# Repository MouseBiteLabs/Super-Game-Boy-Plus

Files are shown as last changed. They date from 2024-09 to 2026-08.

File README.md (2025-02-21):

# Super Game Boy Plus (SGB+)

The Super Game Boy (SGB) was a special cartridge for the Super Nintendo (SNES) that allowed you to play original Game Boy (DMG) games on your Super Nintendo... in **living color!** Some Game Boy games can even take advantage of enhancements provided by the SGB in ways you wouldn't see on a Game Boy, including custom color palettes, enhanced audio, and screen borders. *How does that strike you??*

<p align="center">
<a href="https://youtu.be/XTdGBMhjJ7U?si=7-TzK-MHGgorscUb&t=6">Brace yourself...</a> 
</p>

Unfortunately, the original Super Game Boy had one "major" flaw. The clock speed was 2.4% too fast. For most people, this makes no difference, but for *true gamers* it amounts to blasphemy. The side effect of this is that the Super Game Boy cannot use a link cable to connect with other Game Boys, since the clock speeds would be too dissimilar. Japan got the Super Game Boy 2, which fixed this oversight and added a link port. But everyone else never got it! Thus, true gamers got to work, and created mods that fix the <a href="https://www.qwertymodo.com/hardware-projects/snes/super-game-boy-clock-mod">clock speed</a> and <a href="https://www.qwertymodo.com/hardware-projects/snes/super-game-boy-link-port">add a link port</a>.

Another type of mod that has cropped up over the years <a href="https://www.timeextension.com/news/2023/08/classic-pokemon-games-get-ported-to-snes-by-industrious-fan">are standalone SNES games with a single Game Boy game inside.</a> This generally includes taking the PCB out of a Super Game Boy, taking the PCB out of a Game Boy game (hopefully a reproduction and not an original!), and permanently soldering the Game Boy PCB to the SGB board. A bit rough, but it gets the job done.

The thing about all these different SGB mods is that they consist of boards soldered together to an original SGB board. There hasn't been a single, clean, standalone board that incorporates all these features in a nice, sturdy package. Until now!



This is the Super Game Boy Plus, or SGB+. This circuit board can do the following:

- Allows for three separate clock options:
  1) the original "wrong" clock speed,
  2) the correct clock speed, or
  3) **the correct clock speed with the ability to overclock and underclock in-game**
- Incorporates the link port onto the board using a small daughter board to offset it into a perfect location on the edge of a standard SNES cartridge (if you are using an SGB2 shell, it will fit without the daughter board)
- Optionally allow you to lock the board to one specific Game Boy game instead of using the cartridge connector - save data can be transplanted to/from the cartridge via the FRAM chip
- Can be used in three different SNES shells with minimal shell trimming required:
  1) an original Super Game Boy shell with the cartridge connector,
  2) a standard 46-pin SNES shell (will require two cuts on the bottom of the shell for the extra cart edge pins), and
  3) a 60-pin SNES shell used for games that used enhancement chips like the SA-1 or SuperFX
 
There are two versions of the Super Game Boy Plus - one that can be used for standalone <a href="https://github.com/MouseBiteLabs/Super-Game-Boy-Cartridge/tree/main/SGB-MBC3">MBC3 games</a> (in development), and one that can be used for standalone <a href="https://github.com/MouseBiteLabs/Super-Game-Boy-Cartridge/tree/main/SGB-MBC5">MBC5 games</a>. If you only want an enhanced Super Game Boy without locking it to a single game, you can use *either* the MBC3 or MBC5 variant - it does not matter which you pick. Because this project is highly customizable, you must carefully follow the instructions below to help guide you through the assembly process based on your desires. 

**PLEASE READ THIS GITHUB REPOSITORY IN IT'S ENTIRETY TO ENSURE YOU ASSEMBLE THE CARTRIDGE PROPERLY.**

All gerbers and source files can be found in this repo in the two folders linked above, as this project is fully open source.

## Important Things Before You Start

1) This project requires you remove some components from an original Super Game Boy cartridge. This will require a hot air rework station or a hot plate. This will also require extensive soldering capabilities - do not attempt this project if you do not have sufficient soldering experience.
2) If you are making a single game without the cartridge connector, you need to have an original Game Boy game that uses an MBC3 or MBC5 mapper chip, so you can remove it and use it on this board. <a href="https://catskull.net/gb-rom-database/">You can find a list of games and their mappers here</a>.
3) When soldering parts on, it's a good idea to put kapton tape or otherwise cover the bottom cartridge edge. You do not want to get solder on the cartridge contacts.
4) I am not responsible for any damage you do to your self or your property. Attempt this project at your own risk.
5) I do not guarantee design compatibility. You may encounter issues with certain games. There is also a chance I have made an error in the design or the BOM - if this is the case, I will do everything I can to address the problem as quickly as possible.
6) If you are using this board to make games other than for personal use, you must have permission from the originator to use and distribute any ROM images or other related material. You are responsible for making sure you adhere to any license requirements.

DO NOT use my circuit boards for profiting from stolen work - this especially includes homebrew content, ROM hacks, and using fan-made labels without permission from the originator. **Support ALL original creators!**

## Required Equipment

- You will need basic tools, like a soldering iron, hot plate, and/or hot air rework station.
- If you need the cartridge connector for an enhanced SGB build, <a href="https://hackaday.com/2017/04/03/have-you-ever-tried-desoldering-needles/">desoldering needles</a> may be helpful in removing it from the donor board.
- If you're making a single-game SGB+ cartridge, you will need a method of programming the ROM and FRAM (if desired). You *cannot* program the SGB+ cartridge with a cart programmer, like the OSCR. You need to solder pre-programmed chips.
  - In my opinion, the easiest way to do this if you have the equipment already is to make <a href="https://github.com/MouseBiteLabs/Game-Boy-Cartridges/tree/main/MBC5%20(Type%20A%2C%20FRAM)">one of my FRAM-enabled Game Boy cartridges,</a> and then transfer the ROM and FRAM chips over to the SGB+ board. You can use a variety of cart flashers, such as <a href="https://www.gbxcart.com/">GBxCart</a> and the <a href="https://github.com/sanni/cartreader">OSCR</a> to load the game and save data onto the catridge. Doing it this way, you can also test the game in a Game Boy before you move the chips over to make sure it's in working order. As a bonus, all of the parts on the FRAM board are named *the same* as on the SGB+ board, making part transferrals even easier to manage.
  - Alternatively, the <a href="https://xgecu.myshopify.com/products/xgecu-new-t48-tl866-3gprogrammer-v12-01-support-28000-ics-for-spi-nor-nand-flash-emmc-bga153-162-169-100-221-tsop-sop-plcc">T48 programmer</a> with the <a href="https://xgecu.myshopify.com/products/100-original-xgecu-adp_f48_ex-1-tsop48-special-adapter-for-nor-flash-only-use-on-t48-tl866-3g-programmer">TSOP48 adapter</a> can program the ROM chip.
- If you want to add clock control options (overclocking/underclocking), you will need a way of programming an ATTINY85. My preferred method is to use an <a href="https://store-usa.arduino.cc/collections/boards-modules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">Arduino Uno or Arduino Mega</a>, as I own those already. The instructions I provide will be using an Arduino to program the ATTINY. There are a multitude of other ways as well, but you will need to figure those out for yourself.
- You may need to do some shell cuts to get things to fit, like the link port. I recommend using a file set - <a href="https://www.amazon.com/gp/product/B07R3R9461">I bought this one.</a> 

## Parts from an Original Super Game Boy

These are listed in the BOMs in the MBC3 and MBC5 folders, but for quick reference, you will need:

1) Super Game Boy CPU
2) ICD2 Interface chip
3) SNES Mask ROM (bottom right chip)

These parts are salvagable from the SGB (recommended), but there are alternate options listed in the BOM:
1) 2x SRAM
2) CIC Region Lockout (the 18-pin device in the middle)

PXL_20240821_180204717 MP2

## Assembly Guide

To start off, here is a bird's-eye view of the process to populate one of these boards. Please follow this flowchart as you go. I *highly* recommend testing the board in a SNES after you solder the Group A components. This will help narrow down issues early on, before you start messing with things like overclocking.

<p align="center">

</p>

### Step 1: Getting the Boot Screen

First, populate the entire board with the Group A components. That's the majority of them. Also, solder the CLK1 solder pads on the back of the board to enable the SNES-driven clock just for testing. When you pop it into the SNES (obviously without a Game Boy game), you should see this screen:



If you've got that, then you know you at least got the essentials soldered properly. If you get the Game Boy border, but no cartridge error, then you have some kind of problem somewhere on the GB-side (like the SGB CPU, the ICD2, the RAM chips, etc). If you just get a fully black screen, then either the cartridge might not be making good contact with the SNES cartridge connector (or the cart connector is dirty), or you have some issue with the SNES-side components like the mask ROM or the CIC (if you're using the PIC12F629, make sure the SuperCIC code is programmed properly). You may also have a solder bridge *anywhere* on the board.

### Step 2: Choosing the Clock Generation Method

If you're not planning on fixing the clock speed, and keeping it at the incorrect 4.295 MHz frequency, then you don't have to do anything else for this step. Skip ahead to Step 3! Otherwise, read on.

Note that for all of these clock options, you can populate Group B and C components at the same time without causing any issues. The CLK pads on the back of the board will dictate which of these components have control over the clock generation, and they can't interfere with each other (as long as you only bridge one set of CLK pads).

#### Option 1: Fixed Clock Speed

This is the simplest clock modification, all you have to do is solder the few Group B components, desolder CLK1, and solder bridge CLK2. This will yield the proper clock speed of 4.194 MHz.

#### Option 2: Clock Control With ATTINY85

This one will take some work, because you will need to program the ATTINY85. <a href="https://github.com/MouseBiteLabs/Super-Game-Boy-Cartridge/blob/main/SGB_Clock_Control_ATTINY.ino">You will need to program it with my custom-developed code.</a> You can do this before soldering, or after soldering if you use the ISP header pins. In either case, populate Group C components, desolder CLK1, and solder bridge CLK3 to set up the board for the clock generator.

I will briefly walk through how to program the ATTINY85 after it is soldered to the board, through the ISP header pins, with an Arduino Mega, but you should closely follow the guides I link. If you ask me how to program the chip, or why it isn't programming properly, my answer is going to be "read the tutorial." If you are using a different method of programming, you will have to find instructions yourself.

<a href="https://www.instructables.com/How-to-Program-an-Attiny85-From-an-Arduino-Uno/">Here is detailed instructions for using an Arduino Uno to program an ATTINY85.</a> I haven't used them myself, but they look to be correct. I personally use a Mega to program my ATTINY chips; <a href="https://www.instructables.com/How-to-Burn-ATTiny85-Using-Arduino-Mega/">the detailed instructions can be found here for the Arduino Mega.</a> Again, it is crucial you follow these instructions closely to get it working.

One thing I have done differently than these tutorials in the first steps is the choice of ATTINY core, which you need to communicate with the ATTINY through the Arduino IDE. I use ATTinyCore by SpenceKonde, <a href="https://github.com/SpenceKonde/ATTinyCore">which you can find here</a>. I recommend using this one instead.

Anyway, here's a general guideline for programming the chip:

1. Program the host Arduino to be an ISP programmer. If using the Mega, follow the instructions in the link above to change the pin definitions in the ArduinoISP code to match the Mega instead of the Uno.
2. Put SW1 in PROG mode to allow programming of the ATTINY85.
3. Connect the Arduino pins to the ISP header as such:
  - Connect ISP pin 1 (PB1, PICO on the ATTINY85) to Arduino PICO pin (50 on Mega, 12 on Uno)
  - Connect ISP pin 2 (5V) to the Arduino 5V pin
  - Connect ISP pin 3 (PB2, SCK on the ATTINY85) to Arduino SCK pin (52 on Mega, 13 on Uno)
  - Connect ISP pin 4 (PB0, POCI on the ATTINY85) to Arduino POCI pin (51 on Mega, 11 on Uno)
  - Connect ISP pin 5 (RST, SS on the ATTINY85) to Arduino SS pin (53 on Mega, 10 on Uno)
  - Connect ISP pin 6 (GND) to the Arduino GND pin
4. **Burn the bootloader to the ATTINY85** (Tools > Burn Bootloader). Make sure the processor is set to run on the internal 8 MHz clock, *not* an external clock. Not burning the bootloader is a common cause of failure when people are trying to program these chips.
5. Upload the Arduino sketch provided above onto the ATTINY85. When programming the ATTINY, my drop down menu looks like this:



6. If it uploads correctly, unplug all the wires and **switch SW1 to PLAY mode.** It will not work if it remains in PROG mode.

Remember, if you put the cartridge in your SNES and get a Game Boy border but *no blinking cartridge error* then that means there's an issue with the clock. You will know you did it right if you get the blinking error screen posted above.

#### Option 3: Qwertymodo's Clock Mod

If you don't want to deal with an ATTINY85, the board is fully compatible with <a href="https://www.qwertymodo.com/hardware-projects/snes/super-game-boy-clock-mod">qwertymodo's SGB clock mod</a>. The downside to this is that if you want to change the clock speed, you will still need to buy the Super Game Boy Commander controller from Hori... and those are *not* cheap. The main draw to qwertymodo's mod under normal circumstances is the clock speed is fixed, however since you can fix it pretty easily by soldering in the Group B components, the usefulness is a bit diminished. But in any case, it is still an option. All you have to do is follow the instructions on his site to install it, they apply to my SGB+ boards as well. Make sure the CLK1 pads remain bridged.

### Step 3: Adding a Link Port

Please note that if you want to add the link port, you *must* be using one of the clock options that fix the frequency (this also includes the overclocking option with the ATTINY85, as that defaults to 4.194 MHz). The link port *will not work* if your clock speed is the incorrect 4.295 MHz provided by the SNES.

Firstly, if for some reason you have a junked Japanese-only SGB2 cartridge with an in-tact shell (the blue one that has a cutout for the link port) then you only need to add the link port in the P1 socket. Again, though, the SGB2 is *not* compatible with this mod, so don't buy one as a donor, because you can't use it for parts.



<a href="https://gbhwdb.gekkio.fi/consoles/sgb2/">*Image from gekkio's Game Boy Hardware Database.*</a>

If you are NOT using an SGB2 shell, which I would guess you are not then you'll need to offset the link port from the board vertically to get it to fit in the shell nicely. You will also need to cut out a hole in the SNES shell, obviously.

**PLEASE NOTE: This method will NOT work for Super Famicom or PAL region Super Game Boy cartridges - only for North American SGBs.**



Getting the link port adapter board to sit level is a bit tricky. You also need to make sure the board is placed in the correct way, and not flipped around. The way I do it is:

1) Solder the 2x3 headers (these have 2mm spacing instead of the standard 2.54mm spacing) into the link port adapter board. Make sure the headers are soldered onto the adapter board in such a way that it would be sandwiched between the main PCB and the adapter PCB.


 
2) Solder the 1x2 header (these have the standard 2.54mm spacing) onto the SGB+ board. You will also need to remove the black housing, as that is thicker than the housing on the 2x3 header (which is 1.5mm), so the board would be crooked if this was kept in. Use flush cutters or some other tool to carefully remove them without bending the pins.



3) Optional - place the <a href="https://github.com/MouseBiteLabs/Super-Game-Boy-Cartridge/blob/main/linkadapter_spacer.stl">3D printed spacer I have linked above</a> on top of the SGB+ board to help level the adapter board. If you don't have a 3D printer, you can use *another* link adapter board as a temporary shim (if you get them in the 1.6mm thickness) to achieve approximately the same effect.

4) With the adapter board placed on the main SGB+ board, finish soldering the eight pins - I like to solder the two structural headers, then flip the board over and do the remaining six pins going into the P1 socket on the SGB+ board. Trim down the structural header pins after you're done.



5) Finally, solder the link port onto the adapter board, making sure it's also placed in the right direction on the correct side of the board.

This is how it should look from the "topside" of the board. (Note that this picture does not include the 3D printed spacer.)



I detail shell trimming farther down.

### Step 4: Adding the Game Boy Components

If you're planning on retaining the cartridge connector in your build, then solder in the cartridge connector now! I recommend taking the time to clean it out with some isopropyl alcohol to get better contact with Game Boy carts, since you've got it outside the shell anyway. Then, you're done! (This is the only Group E component)



If you're planning on locking the cartridge to a single game, then you have some more work to do. You need to program the M29F160 chip with the ROM of the game you want to make. You can do this in one of two ways:

1) With a standalone programmer like the <a href="https://xgecu.myshopify.com/products/xgecu-new-t48-tl866-3gprogrammer-v12-01-support-28000-ics-for-spi-nor-nand-flash-emmc-bga153-162-169-100-221-tsop-sop-plcc">T48 programmer</a> with the <a href="https://xgecu.myshopify.com/products/100-original-xgecu-adp_f48_ex-1-tsop48-special-adapter-for-nor-flash-only-use-on-t48-tl866-3g-programmer">TSOP48 adapter</a> - just place the chip in the adapter, load the ROM file in the programming software, and flash the chip

OR

2) Build a Game Boy cartridge that uses the M29F160 (like my FRAM MBC3 boards, or <a href="https://github.com/MouseBiteLabs/Game-Boy-Cartridges/tree/main/MBC5%20(Type%20A%2C%20FRAM)">FRAM MBC5 boards</a>), flash the game using a cart flasher like the <a href="https://www.gbxcart.com/">GBxCart</a> or the <a href="https://github.com/sanni/cartreader">OSCR</a>, then desolder the chips and move them over to the SGB+ board. Note that for my FRAM boards, I use the same reference designators on the Game Boy boards as I do on these SGB+ boards, making matching up the parts a lot easier if you're transferring them over. *(Note: the following picture is an old design where the reference designators are different. Ignore it!)*



The upside to #2 is that you can test the game out in an actual Game Boy before transferring the chips over, and you can flash save data onto the FRAM if you have a game already started on a different cartridge you've dumped. So personally, I use method #2 if I can.

After you've programmed your ROM (and optionally FRAM) chip(s), then solder them to the board, along with the rest of the Group F components.

**Note: The board will not fit in a Super Game Boy shell if you have soldered in the Group F components.**



At this point - you've completed assembly of the cartridge electronics! Test it in a SNES to make sure it works properly.

## Shell Trimming

As mentioned, other than the SGB2 shell, there are three different shells this circuit board is compatible with: an original Super Game Boy shell with the cartridge connector, a standard 46-pin SNES shell, and a 60-pin SNES shell used for games that used enhancement chips like the SA-1 or SuperFX. This section will go over the (potential) shell cuts you may need for your build, depending on what features you're including and which shell you're using. (Spoiler alert: the 60-pin shells require the fewest amount of cuts.)

### Super Game Boy Shell Trimming (for Link Port)

Along with the trimming below for the link port, you will need to do a few minor trims on the SGB shell if you're making an enhanced SGB cartridge, that I recommend tackling first before you move onto the big trim.

There's this ridge here near where the link port will be going on the back shell. This doesn't need to be an extremely clean cut.



On the front shell, you will also need to trim off this post, as it interferes with the link port board.



Now to cover the actual trimming required for letting the link port stick out, which will be applicable to all the shell types.

### Link Port Shell Trimming

If you are adding a link port, and you aren't using an SGB2 shell, you will need to do a cut on every shell to accomodate the link port. <a href="https://github.com/MouseBiteLabs/Super-Game-Boy-Cartridge/blob/main/linkport_cut_guide.stl">I've created a 3D model you can 3D print in order to help line up the cut you need to make</a>; it is also linked at the top of this repository. The print sits on top of the shell and has a cutout where you can start your cut for the link port. Note that this is **only** a starting point. You will need to shave back the shell more to get it to fit - go slowly, be patient, or you will get ugly cuts. Cut the area highlighted in yellow below.



You should also do a cut on the *top* half of the shell, where the link port will sit, to make sure it closes nicely. I don't have a guide made up for this one, since it's a pretty minor cut. Just line it up, and shave off the section.



### Standard 46-pin SNES Shell Cuts

Standard SNES shells only have one cut on the bottom of the shell to allow the middle 46 cart edge pins to stick through. But the Super Game Boy uses the extra 16 expansion pins on either end. So you'll have to cut two slots for those parts of the cart edge to stick through. The easiest way I've been able to do this is to line up the middle 46 pins, and sit the board a bit above that so you can see the plastic you'll need to cut. Then, mark the area you'll have to cut with a marker, and go over it with a file. I *highly* recommend against using flush cutters to make a starting cut, because the plastic will snap off really easily all the way towards the middle, and you'll be missing the two little nubs.





## Game Controls

Since this is still a Super Game Boy... probably just good to look at the <a href="https://archive.org/details/nintendo-snes-super-game-boy/mode/2up">Super Game Boy manual</a> for all the controls that go with that.

Other than that - if you've installed the clock mod onto your board, this is how you control it if you use the code I provide. You only need to use the Start and Select buttons to change speeds. In the code, I have allocated space for seven different clock settings, and it starts at 1x by default (the correct 4.194 MHz clock speed). Note that each clock speed will affect the audio as well - it is not like Dodrio mode in Pokemon Stadium's GB Tower where the audio is unaffected. This means playing games can get... annoying at really high clock speeds.

The default clock multiplier settings are in order: 0.5x, 0.67x, 0.8x, 1x, 1.25x, 1.5x, 2x. A clock multiplier of 3x works, but produces a lot of graphical glitches. 4x and higher becomes unstable and will freeze the game.

- Speeding up: Press and hold Select first, wait a second, then also press and hold Start simultaneously (imitating a "fast forward" button)
- Slowing down: Press and hold Start first, wait a second, then also press and hold Select simultaneously (imitating a "rewind" button)
- Continuing to hold these two buttons down will continue up/down the list of clock multipliers in the code until it hits the maximum/minimum, with approximately a 2 second delay between switching





If you want, you can also disable the clock change function, allowing you to use the Start and Select buttons freely (though, I can't think of any game that requires you press these buttons simultaneously for longer than a few seconds). To do this:

- Press and hold both Start *and* Select at the same time and hold down for approximately 5 seconds.
- If your clock speed is something other than the 1x setting, it will be reset back to 1x.
- At this point, you have disabled the clock change function: **pressing Start/Select will no longer change the clock speed.**
- To re-enable clock control, press and hold Start *and* Select at the same time and hold down for approximately 5 seconds.

Power cycling the SNES will also re-enable the clock control function.

## FAQ

**Q: Will these boards fit in Super Famicom shells?**

A: I am pretty sure they do, but I don't have any to try out. If you're able to confirm they fit for me, please let me know, and I will update this question accordingly.

**Q: Does this work with a DMG CPU instead of a SGB CPU?**

A: Unfortunately, no, but it would be really nice if you could.

**Q: Does this work with a SGB2 CPU instead of a SGB CPU?**

A: No, please do not destroy a SGB2 for this project!

**Q: Can you make one for me?**

A: No.

**Q: But what if I pay you?**

A: **NO.**

**Q: Can I make Game Boy Color games with this?**

A: No.

**Q: Can you make a board that lets you play Game Boy Color games on the SNES?**

A: Not without FPGA wizardry, which is something I don't want to deal with.

## Resources and Acknowledgements

- Enormous thanks to Gekkio for their Super Game Boy reverse engineering work. <a href="https://github.com/Gekkio/gb-schematics/tree/main/SGB-R-xx_SGB-N-xx">This repository</a> was the basis of this project, and he saved me hours and hours of time. He is the hero we don't deserve.
- <a href="https://www.qwertymodo.com/">Qwertymodo</a>'s work with the clock mod and link port additions really helped me out in designing my own. Huge thanks for his findings, and all he has contributed to the gaming space!
- Thanks to Adafruit for providing the basis of the <a href="https://learn.adafruit.com/adafruit-si5351-clock-generator-breakout/overview">clock generator circuit.</a>
- Special thanks to beta tester olDirdey from discord, for providing some feedback on the link port and suggesting the 2-pin structural support header.

## License

<br />This work is licensed under a <a rel="license" href="http://creativecommons.org/licenses/by-sa/4.0/">Creative Commons Attribution-ShareAlike 4.0 International License</a>. You are able to copy and redistribute the material in any medium or format, as well as remix, transform, or build upon the material for any purpose (even commercial) - but you **must** give appropriate credit, provide a link to the license, and indicate if any changes were made.

©MouseBiteLabs 2024

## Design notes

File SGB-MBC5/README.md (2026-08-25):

# MBC5 Variant

This board is the MBC5 variant, useful for making standalone MBC5-based Game Boy games for the Super Nintendo. You can *also* use this board *completely without* the Game Boy parts to make an enhanced SGB board with link port and modified clock.

## Board Characteristics and Order Information

The zipped folder contains all the gerber files for this board. The following options **must** be chosen when ordering boards for yourself.

- Thickness: 1.2mm
- Layers: 4
- Surface Finish: ENIG
- Gold Fingers: Yes, 30° chamfer

You can use the zipped folder at any board fabricator you like. You may also buy the board from PCBWay using this link (disclosure: I receive 10% of the sale value to go towards future PCB orders of my own):

<a href="https://www.pcbway.com/project/shareproject/Super_Game_Boy_Plus_2783d5a1.html">PCB from PCBWay</a>

**PLEASE NOTE: I have not ordered these from PCBWay, so I cannot attest to their quality or performance. I have put the order details in as I believe they should be, but you need to review all parameters before ordering. Order at your own risk.**

### Purchase from My Website

You can purchase this circuit board at my website, [https://mousebitelabs.store](https://mousebitelabs.store). Click the following image to be directed to the specific item listing:

<a href="https://mousebitelabs.store/products/super-game-boy-plus-circuit-board-mbc5">PCB from MouseBiteLabs</a>

### Purchase from Etsy

I also offer the board on Etsy, if you would rather purchase through there - click the banner to be redirected.

<a href="https://mousebitelabs.etsy.com/listing/1837439505">PCB from Etsy</a> 

## Bill of Materials (BOM)

Here's a Mouser cart that has every part you would need on the circuit board, *except* the parts you must harvest from a Super Game Boy cartridge and an MBC5 Game Boy cartridge. It also does not include a link port, since you will need to get that from aftermarket sellers (check the link in the BOM). 

If your Super Game Boy cartridge has damaged RAM chips (something that is unlikely, but possible), you will also need to add the RAM chips listed in the BOM.

https://www.mouser.com/ProjectManager/ProjectDetail.aspx?AccessID=6f87901e1f 

If you don't need all of the component groups below, you will need to go through the cart and remove the ones you do not need. Note that the FRAM itself is >$10 at the time of writing. You can get cheaper parts from other sellers on eBay or AliExpress, but the quality is dubious, so order at your own risk.

### Group A Components (Required for Every Build)
| Reference | Value/Part Number | Package | Description | Source |
| --- | --- | --- | --- | --- |
| C1 | 0.01uF | 0603 | Capacitor (MLCC) | https://mou.sr/3AsRwK1 |
| C2 | 0.01uF | 0603 | Capacitor (MLCC) | https://mou.sr/3AsRwK1 |
| C3 | 0.01uF | 0603 | Capacitor (MLCC) | https://mou.sr/3AsRwK1 |
| C4 | 0.01uF | 0603 | Capacitor (MLCC) | https://mou.sr/3AsRwK1 |
| C5 | 0.01uF | 0603 | Capacitor (MLCC) | https://mou.sr/3AsRwK1 |
| C6 | 0.01uF | 0603 | Capacitor (MLCC) | https://mou.sr/3AsRwK1 |
| C7 | 22uF | 4mm x 5.5mm | Capacitor (ALEL) | https://mou.sr/4cVQXbO |
| C8 | 4.7uF | 4mm x 5.5mm | Capacitor (ALEL) | https://mou.sr/4cRhEhW |
| C9 | 4.7uF | 4mm x 5.5mm | Capacitor (ALEL) | https://mou.sr/4cRhEhW |
| C10 | 0.1uF | 0603 | Capacitor (MLCC) | https://mou.sr/3ENc15O |
| C11 | 0.1uF | 0603 | Capacitor (MLCC) | https://mou.sr/3ENc15O |
| C13 | 10pF | 0603 | Capacitor (MLCC) | https://mou.sr/3XA5J3N |
| C14 | 10pF | 0603 | Capacitor (MLCC) | https://mou.sr/3XA5J3N |
| C15 | 33pF | 0603 | Capacitor (MLCC) | https://mou.sr/4cYZLxw |
| C16 | 51pF | 0603 | Capacitor (MLCC) | https://mou.sr/3XjvPGV |
| C17 | 51pF | 0603 | Capacitor (MLCC) | https://mou.sr/3XjvPGV |
| C18 | 0.01uF | 0603 | Capacitor (MLCC) | https://mou.sr/3AsRwK1 |
| R1 | 510k | 0603 | Resistor | https://mou.sr/3zi8ayj |
| R2 | 910 | 0603 | Resistor | https://mou.sr/4gj68i7 |
| R3 | 910 | 0603 | Resistor | https://mou.sr/4gj68i7 |
| R4 | 220 | 0603 | Resistor | https://mou.sr/3ARwrf3 |
| R5 | 220 | 0603 | Resistor | https://mou.sr/3ARwrf3 |
| R6 | 220 | 0603 | Resistor | https://mou.sr/3ARwrf3 |
| R7 | 510 | 0603 | Resistor | https://mou.sr/3IJHtni |
| R8 | 10k | 0603 | Resistor | https://mou.sr/3riR7IH |
| R9 | 330 | 0603 | Resistor | https://mou.sr/3PWP8Ti |
| R10 | 330 | 0603 | Resistor | https://mou.sr/3PWP8Ti |
| R11 | 330 | 0603 | Resistor | https://mou.sr/3PWP8Ti |
| R12 | 330 | 0603 | Resistor | https://mou.sr/3PWP8Ti |
| R13 | 330 | 0603 | Resistor | https://mou.sr/3PWP8Ti |
| R14 | 330 | 0603 | Resistor | https://mou.sr/3PWP8Ti |
| R15 | 330 | 0603 | Resistor | https://mou.sr/3PWP8Ti |
| R16 | 330 | 0603 | Resistor | https://mou.sr/3PWP8Ti |
| R28 | 10k | 0603 | Resistor | https://mou.sr/3riR7IH |
| U1 | CPU SGB | QFP-80 | Super Game Boy CPU | Donor Super Game Boy |
| U2 | ICD2 | QFP-44 | SGB-SNES Interface Chip | Donor Super Game Boy |
| U3 | LH52A64N / AS6C6264 | SOIC-28 | 64K SRAM | Donor Super Game Boy / https://mou.sr/4cWBw3f |
| U4 | LH52A64N / AS6C6264 | SOIC-28 | 64K SRAM | Donor Super Game Boy / https://mou.sr/4cWBw3f |
| U5 | SYS-SGB | SOIC-32 | Mask ROM (SNES) | Donor Super Game Boy |
| U6 | CIC / PIC12F629 | SSOP-18 / SOIC-8 | Lockout Chip | Donor Super Game Boy / https://mou.sr/4dSUh90 |

### Group B Components (For a Fixed 4.194304 MHz Clock)
| Reference | Value/Part Number | Package | Description | Source |
| --- | --- | --- | --- | --- |
| C23 | 27pF | 0603 | Capacitor (MLCC) | https://mou.sr/3XiK3HJ |
| C24 | 27pF | 0603 | Capacitor (MLCC) | https://mou.sr/3XiK3HJ |
| R18 | 1M | 0603 | Resistor | https://mou.sr/3xhFdS3 |
| X1 | 4.194304 MHz | HC-49/US | Crystal Oscillator | https://mou.sr/3yXaoDq |

### Group C Components (For a Fixed 4.194304 MHz Clock, with Overclocking and Underclocking)
| Reference | Value/Part Number | Package | Description | Source |
| --- | --- | --- | --- | --- |
| C30 | 1uF | 0603 | Capacitor (MLCC) | https://mou.sr/47lY3oP |
| C31 | 0.1uF | 0603 | Capacitor (MLCC) | https://mou.sr/3ENc15O |
| C32 | 0.1uF | 0603 | Capacitor (MLCC) | https://mou.sr/3ENc15O |
| C33 | 0.1uF | 0603 | Capacitor (MLCC) | https://mou.sr/3ENc15O |
| Q1 | BSS138 | SOT-23 | MOSFET (N-ch) | https://mou.sr/3TjlOs3 |
| Q2 | BSS138 | SOT-23 | MOSFET (N-ch) | https://mou.sr/3TjlOs3 |
| SW1 | CAS-220A1 | A-type | DPDT | https://mou.sr/4ewSJSb |
| U11 | NCP161ASN330T1G | SOT-23-5 | 3.3V Regulator | https://mou.sr/3iqSHDt |
| U12 | Si5351A-B-GT | MSOP-10 | Clock Generator | https://mou.sr/3Wyr1LG |
| U13 | ATTINY85 | SOIC-8 | Microcontroller | https://mou.sr/3OpMtBA |
| X2 | 25.000 MHz | 3.2mm x 2.5mm | Crystal Oscillator | https://mou.sr/3MAK5pD |

### Group D Components (For Adding a Link Port)
| Reference | Value/Part Number | Package | Description | Source |
| --- | --- | --- | --- | --- |
| A1 | Link Adapter PCB v1.3 | N/A | Adapter circuit board | |
| C25 | 100pF | 0603 | Capacitor (MLCC) | https://mou.sr/47fshd2 |
| C26 | 100pF | 0603 | Capacitor (MLCC) | https://mou.sr/47fshd2 |
| C27 | 100pF | 0603 | Capacitor (MLCC) | https://mou.sr/47fshd2 |
| C28 | 100pF | 0603 | Capacitor (MLCC) | https://mou.sr/47fshd2 |
| C29 | 0.01uF | 0603 | Capacitor (MLCC) | https://mou.sr/3AsRwK1 |
| D1 | BAV99S | SOT-363 | Dual series diodes | https://mou.sr/3X97NOE |
| D2 | BAV99S | SOT-363 | Dual series diodes | https://mou.sr/3X97NOE |
| D3 | ES07D | SMF | Diode | https://mou.sr/3XdX1Xr |
| J1 | 610106249121 | 2x3, 2.54mm spacing, right angle | Programming header | https://mou.sr/3XygS4Z |
| J2 | G800WC306018EU | 1x2, 2.54mm spacing | Header pins (structural) | https://mou.sr/3yXak6E |
| J3 | 2MM-HB-D03-VT-02-H-TB | 2x3, 2mm spacing | Header pins (link port PCB) | https://mou.sr/3TfU2wA |
| P2 | Link Port | 2x3, 2mm spacing | MGB/GBC Link Port | https://tinyurl.com/m3y35e3z |
| R19 | 220 | 0603 | Resistor | https://mou.sr/3ARwrf3 |
| R20 | 220 | 0603 | Resistor | https://mou.sr/3ARwrf3 |
| R21 | 220 | 0603 | Resistor | https://mou.sr/3ARwrf3 |
| R22 | 220 | 0603 | Resistor | https://mou.sr/3ARwrf3 |
| R23 | 10k | 0603 | Resistor | https://mou.sr/3riR7IH |
| R24 | 10k | 0603 | Resistor | https://mou.sr/3riR7IH |
| R25 | 10k | 0603 | Resistor | https://mou.sr/3riR7IH |
| R26 | 10k | 0603 | Resistor | https://mou.sr/3riR7IH |
| R27 | 10k | 0603 | Resistor | https://mou.sr/3riR7IH |

### Group E Components (For an Enhanced SGB Board)
| Reference | Value/Part Number | Package | Description | Source |
| --- | --- | --- | --- | --- |
| P1 | Game Boy Cart Connector | N/A | SGB Game Boy Cart Connector | Donor Super Game Boy |

### Group F Components (For a Single-Game SGB Board)
| Reference | Value/Part Number | Package | Description | Source |
| --- | --- | --- | --- | --- |
| C19 | 0.1uF | 0603 | Capacitor (MLCC) | https://mou.sr/3ENc15O |
| C20 | 0.1uF | 0603 | Capacitor (MLCC) | https://mou.sr/3ENc15O |
| C21 | 0.1uF | 0603 | Capacitor (MLCC) | https://mou.sr/3ENc15O |
| C22 | 0.1uF | 0603 | Capacitor (MLCC) | https://mou.sr/3ENc15O |
| R17 | 10k | 0603 | Resistor | https://mou.sr/3riR7IH |
| U7 | M29F160 | TSOP-48 | Flash EEPROM (Game Boy) | https://mou.sr/3N0a9eL |
| U8 | MBC5 | QFP-32 | MBC5 Mapper | Donor Game Boy Game |
| U9 | FM18W08-SG | SOIC-28 | FRAM | https://mou.sr/4cRIJlb |
| U10 | SN74LVC1G332 | SOT-363 | 3-input Or Gate | https://mou.sr/3XdbXoN |

### Other Components - Do Not Populate
| Reference | Value/Part Number | Package | Description | Group | Source |
| --- | --- | --- | --- | ----- | --- |
| C12 | 10pF (DNP) | 0603 | Capacitor (MLCC) | DNP | https://mou.sr/3XA5J3N |
## License

<br />This work is licensed under a <a rel="license" href="http://creativecommons.org/licenses/by-sa/4.0/">Creative Commons Attribution-ShareAlike 4.0 International License</a>. You are able to copy and redistribute the material in any medium or format, as well as remix, transform, or build upon the material for any purpose (even commercial) - but you **must** give appropriate credit, provide a link to the license, and indicate if any changes were made.

©MouseBiteLabs 2024

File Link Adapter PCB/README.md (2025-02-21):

# Link Adapter PCB

Use this board to center the link port properly in SNES shells that *aren't* the SGB2.

NOTE: This only works on the North American Super Game Boy shell. It will not fit in a Super Famicom or PAL region SGB.

## Board Characteristics and Order Information

The zipped folder contains all the gerber files for this board. The board characteristics don't really matter a whole lot, but I would err on the thicker side for support purposes.

- Thickness: any
- Layers: 2
- Surface Finish: any

<a href="https://oshpark.com/shared_projects/MZ2FDhuA">Also available on OSH Park.</a>

## Board Explanation

Please review the main guide for instructions on how to install the board. Here is a quick reference for the board to help you keep it straight, and to not install it incorrectly.



## License

<br />This work is licensed under a <a rel="license" href="http://creativecommons.org/licenses/by-sa/4.0/">Creative Commons Attribution-ShareAlike 4.0 International License</a>. You are able to copy and redistribute the material in any medium or format, as well as remix, transform, or build upon the material for any purpose (even commercial) - but you **must** give appropriate credit, provide a link to the license, and indicate if any changes were made.

©MouseBiteLabs 2024

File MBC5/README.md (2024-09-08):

# MBC5 Variant

## Bill of Materials (BOM)

| Reference | Value/Part Number | Package | Description | Group | Source |
| --- | --- | --- | --- | ----- | --- |
| C1 | 0.01uF | 0603 | Capacitor (MLCC) | A | https://mou.sr/3AsRwK1 |
| C2 | 0.01uF | 0603 | Capacitor (MLCC) | A | https://mou.sr/3AsRwK1 |
| C3 | 0.01uF | 0603 | Capacitor (MLCC) | A | https://mou.sr/3AsRwK1 |
| C4 | 0.01uF | 0603 | Capacitor (MLCC) | A | https://mou.sr/3AsRwK1 |
| C5 | 0.01uF | 0603 | Capacitor (MLCC) | A | https://mou.sr/3AsRwK1 |
| C6 | 0.01uF | 0603 | Capacitor (MLCC) | A | https://mou.sr/3AsRwK1 |
| C7 | 22uF | 4mm x 5.5mm | Capacitor (ALEL) | A | https://mou.sr/4cVQXbO |
| C8 | 4.7uF | 4mm x 5.5mm | Capacitor (ALEL) | A | https://mou.sr/4cRhEhW |
| C9 | 4.7uF | 4mm x 5.5mm | Capacitor (ALEL) | A | https://mou.sr/4cRhEhW |
| C10 | 0.1uF | 0603 | Capacitor (MLCC) | A | https://mou.sr/3ENc15O |
| C11 | 0.1uF | 0603 | Capacitor (MLCC) | A | https://mou.sr/3ENc15O |
| C12 | 10pF (DNP) | 0603 | Capacitor (MLCC) | DNP | https://mou.sr/3XA5J3N |
| C13 | 10pF | 0603 | Capacitor (MLCC) | A | https://mou.sr/3XA5J3N |
| C14 | 10pF | 0603 | Capacitor (MLCC) | A | https://mou.sr/3XA5J3N |
| C15 | 33pF | 0603 | Capacitor (MLCC) | A | https://mou.sr/4cYZLxw |
| C16 | 51pF | 0603 | Capacitor (MLCC) | A | https://mou.sr/3XjvPGV |
| C17 | 51pF | 0603 | Capacitor (MLCC) | A | https://mou.sr/3XjvPGV |
| C18 | 0.01uF | 0603 | Capacitor (MLCC) | A | https://mou.sr/3AsRwK1 |
| C19 | 0.1uF | 0603 | Capacitor (MLCC) | F | https://mou.sr/3ENc15O |
| C20 | 0.1uF | 0603 | Capacitor (MLCC) | F | https://mou.sr/3ENc15O |
| C21 | 0.1uF | 0603 | Capacitor (MLCC) | F | https://mou.sr/3ENc15O |
| C22 | 0.1uF | 0603 | Capacitor (MLCC) | F | https://mou.sr/3ENc15O |
| C23 | 27pF | 0603 | Capacitor (MLCC) | B | https://mou.sr/3XiK3HJ |
| C24 | 27pF | 0603 | Capacitor (MLCC) | B | https://mou.sr/3XiK3HJ |
| C25 | 100pF | 0603 | Capacitor (MLCC) | D | https://mou.sr/47fshd2 |
| C26 | 100pF | 0603 | Capacitor (MLCC) | D | https://mou.sr/47fshd2 |
| C27 | 100pF | 0603 | Capacitor (MLCC) | D | https://mou.sr/47fshd2 |
| C28 | 100pF | 0603 | Capacitor (MLCC) | D | https://mou.sr/47fshd2 |
| C29 | 0.01uF | 0603 | Capacitor (MLCC) | D | https://mou.sr/3AsRwK1 |
| C30 | 1uF | 0603 | Capacitor (MLCC) | C | https://mou.sr/47lY3oP |
| C31 | 0.1uF | 0603 | Capacitor (MLCC) | C | https://mou.sr/3ENc15O |
| C32 | 0.1uF | 0603 | Capacitor (MLCC) | C | https://mou.sr/3ENc15O |
| C33 | 0.1uF | 0603 | Capacitor (MLCC) | C | https://mou.sr/3ENc15O |
| D1 | BAV99S | SOT-363 | Dual series diodes | D | https://mou.sr/3X97NOE |
| D2 | BAV99S | SOT-363 | Dual series diodes | D | https://mou.sr/3X97NOE |
| D3 | ES07D | SMF | Diode | D | https://mou.sr/3XdX1Xr |
| J1 | 2MM-HB-D03-VT-02-H-TB | 2x3, 2mm spacing | Header pins | D | https://mou.sr/3TfU2wA |
| J2 | G800WC306018EU | 1x2, 2.54mm spacing | Header pins | D | [https://mou.sr/3yXak6E](https://mou.sr/3yXak6E) |
| P1 | Link Port | 2x3, 2mm spacing | Link Port | D | [https://tinyurl.com/m3y35e3z](https://tinyurl.com/m3y35e3z) |
| Q1 | BSS138 | SOT-23 | MOSFET (N-ch) | C | https://mou.sr/3TjlOs3 |
| Q2 | BSS138 | SOT-23 | MOSFET (N-ch) | C | https://mou.sr/3TjlOs3 |
| R1 | 510k | 0603 | Resistor | A | https://mou.sr/3zi8ayj |
| R2 | 910 | 0603 | Resistor | A | https://mou.sr/4gj68i7 |
| R3 | 910 | 0603 | Resistor | A | https://mou.sr/4gj68i7 |
| R4 | 220 | 0603 | Resistor | A | https://mou.sr/3ARwrf3 |
| R5 | 220 | 0603 | Resistor | A | https://mou.sr/3ARwrf3 |
| R6 | 220 | 0603 | Resistor | A | https://mou.sr/3ARwrf3 |
| R7 | 510 | 0603 | Resistor | A | https://mou.sr/3IJHtni |
| R8 | 10k | 0603 | Resistor | A | https://mou.sr/3riR7IH |
| R9 | 330 | 0603 | Resistor | A | https://mou.sr/3PWP8Ti |
| R10 | 330 | 0603 | Resistor | A | https://mou.sr/3PWP8Ti |
| R11 | 330 | 0603 | Resistor | A | https://mou.sr/3PWP8Ti |
| R12 | 330 | 0603 | Resistor | A | https://mou.sr/3PWP8Ti |
| R13 | 330 | 0603 | Resistor | A | https://mou.sr/3PWP8Ti |
| R14 | 330 | 0603 | Resistor | A | https://mou.sr/3PWP8Ti |
| R15 | 330 | 0603 | Resistor | A | https://mou.sr/3PWP8Ti |
| R16 | 330 | 0603 | Resistor | A | https://mou.sr/3PWP8Ti |
| R17 | 10k | 0603 | Resistor | F | https://mou.sr/3riR7IH |
| R18 | 1M | 0603 | Resistor | B | https://mou.sr/3xhFdS3 |
| R19 | 220 | 0603 | Resistor | D | https://mou.sr/3ARwrf3 |
| R20 | 220 | 0603 | Resistor | D | https://mou.sr/3ARwrf3 |
| R21 | 220 | 0603 | Resistor | D | [https://mou.sr/3ARwrf3](https://mou.sr/3ARwrf3) |
| R22 | 220 | 0603 | Resistor | D | https://mou.sr/3ARwrf3 |
| R23 | 10k | 0603 | Resistor | D | https://mou.sr/3riR7IH |
| R24 | 10k | 0603 | Resistor | D | https://mou.sr/3riR7IH |
| R25 | 10k | 0603 | Resistor | D | https://mou.sr/3riR7IH |
| R26 | 10k | 0603 | Resistor | D | https://mou.sr/3riR7IH |
| R27 | 10k | 0603 | Resistor | D | https://mou.sr/3riR7IH |
| R28 | 10k | 0603 | Resistor | A | https://mou.sr/3riR7IH |
| SW1 | CAS-220A1 | A-type | DPDT | C | https://mou.sr/4ewSJSb |
| U1 | CPU SGB | QFP-80 | Super Game Boy CPU | A | Donor SGB |
| U2 | ICD2 | QFP-44 | SGB-SNES Interface Chip | A | Donor SGB |
| U3 | AS6C6264 | SOIC-28 | 64K SRAM | A | https://mou.sr/4cWBw3f |
| U4 | AS6C6264 | SOIC-28 | 64K SRAM | A | https://mou.sr/4cWBw3f |
| U5 | SYS-SGB | SOIC-32 | Mask ROM (SNES) | A | Donor SGB |
| U6 | CIC / PIC12F629 | SSOP-18 / SOIC-8 | Lockout Chip | A | Donor SGB / https://mou.sr/4dSUh90 |
| U7 | M29F160 | TSOP-48 | Flash EEPROM (Game Boy) | F | https://mou.sr/3N0a9eL |
| U8 | MBC5 | QFP-32 | MBC5 Mapper | F | Donor Game Boy Game |
| U9 | FM18W08-SG | SOIC-28 | FRAM | F | https://mou.sr/4cRIJlb |
| U10 | SN74LVC1G332 | SOT-363 | 3-input Or Gate | F | https://mou.sr/3XdbXoN |
| U11 | NCP161ASN330T1G | SOT-23-5 | 3.3V Regulator | C | https://mou.sr/3iqSHDt |
| U12 | Si5351A-B-GT | MSOP-10 | Clock Generator | C | https://mou.sr/3Wyr1LG |
| U13 | ATTINY85 | SOIC-8 | Microcontroller | C | https://mou.sr/3OpMtBA |
| X1 | 4.194304 MHz | HC-49/US | Crystal Oscillator | B | [https://mou.sr/3yXaoDq](https://mou.sr/3yXaoDq) |
| X2 | 25.000 MHz | 3.2mm x 2.5mm | Crystal Oscillator | C | https://mou.sr/3MAK5pD |

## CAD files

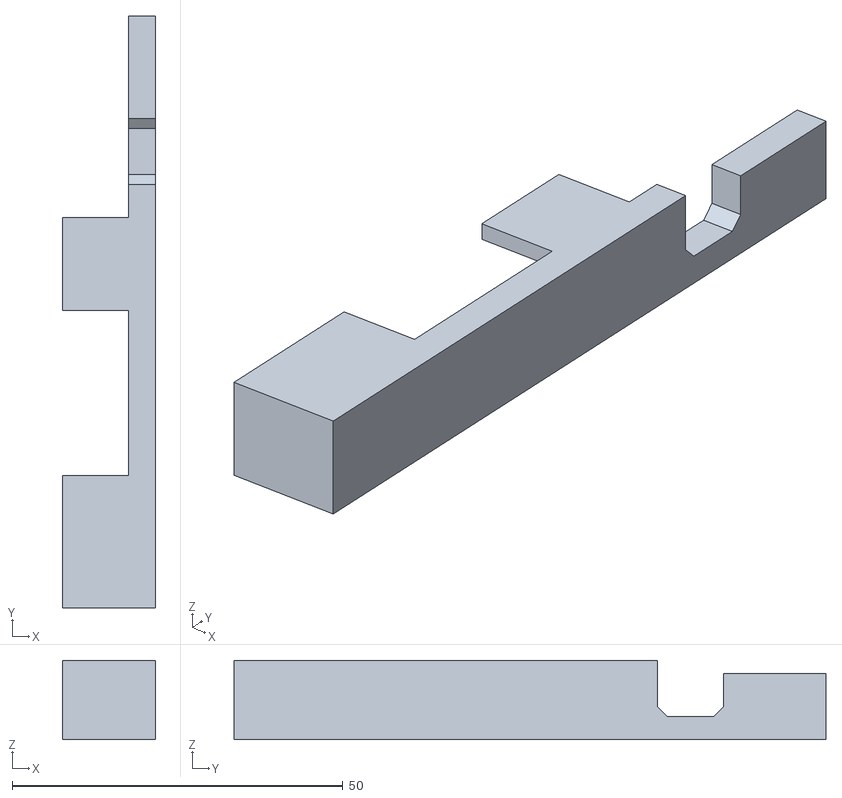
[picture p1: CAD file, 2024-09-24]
linkport_cut_guide.stl
14.1 x 89.5 x 12.0

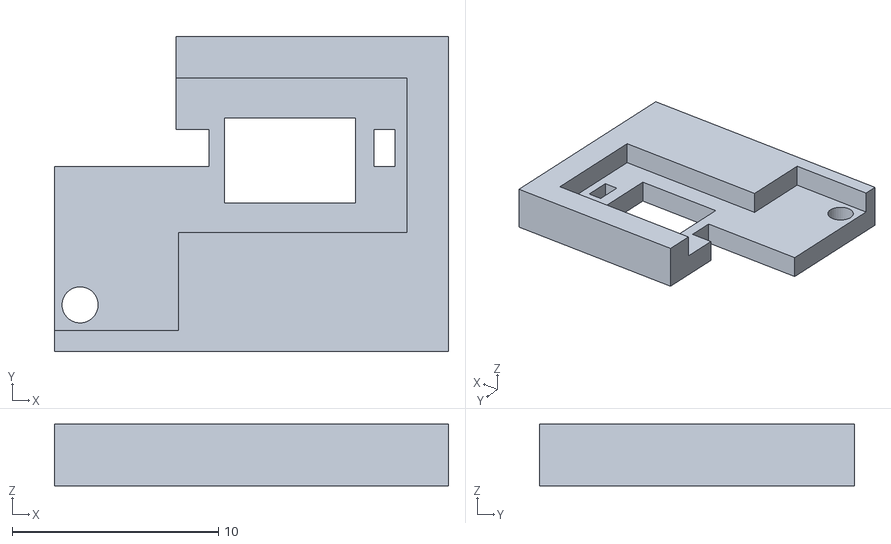
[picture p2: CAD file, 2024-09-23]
linkadapter_spacer.stl
19.1 x 15.3 x 3.00

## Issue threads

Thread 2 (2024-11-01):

External Switch to Toggle Between Internal ROM and Cartridge Slot on the Super Game Boy

FokinoPelvis, 2024-11-01:
I would like to suggest a hardware modification for the Super Game Boy Plus that could significantly enhance its usability and versatility. Specifically, I propose adding a switch on the side of the Super Game Boy's casing, with two selectable positions:

Internal ROM Mode: This position would allow users to directly access the Super Game Boy Plus’s built-in ROM, bypassing the need for a cartridge.

Cartridge Slot Mode: This position would allow the system to read any cartridge inserted into the slot, as is the current standard. Ideally, if no cartridge is inserted, the system could default back to the internal ROM. However, I understand that automating this process may present technical challenges.

This addition would enable users to effortlessly switch between internal content and cartridge games without needing complex modifications or additional tools. I believe this feature would add substantial value to the Super Game Boy Plus and offer users a more seamless gaming experience.

Thank you for considering this enhancement, and I appreciate your ongoing commitment to improving the Super Game Boy Plus.

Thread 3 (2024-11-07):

Trying to have it made through your shared project on pcbway but there are clearance problems.

noromamai, 2024-11-07:
The minimum clearance of the project files is 0.15mm, but none of their solder masks they offer can go lower than 0.19mm. Is it ok to produce the pcb without solder mask?

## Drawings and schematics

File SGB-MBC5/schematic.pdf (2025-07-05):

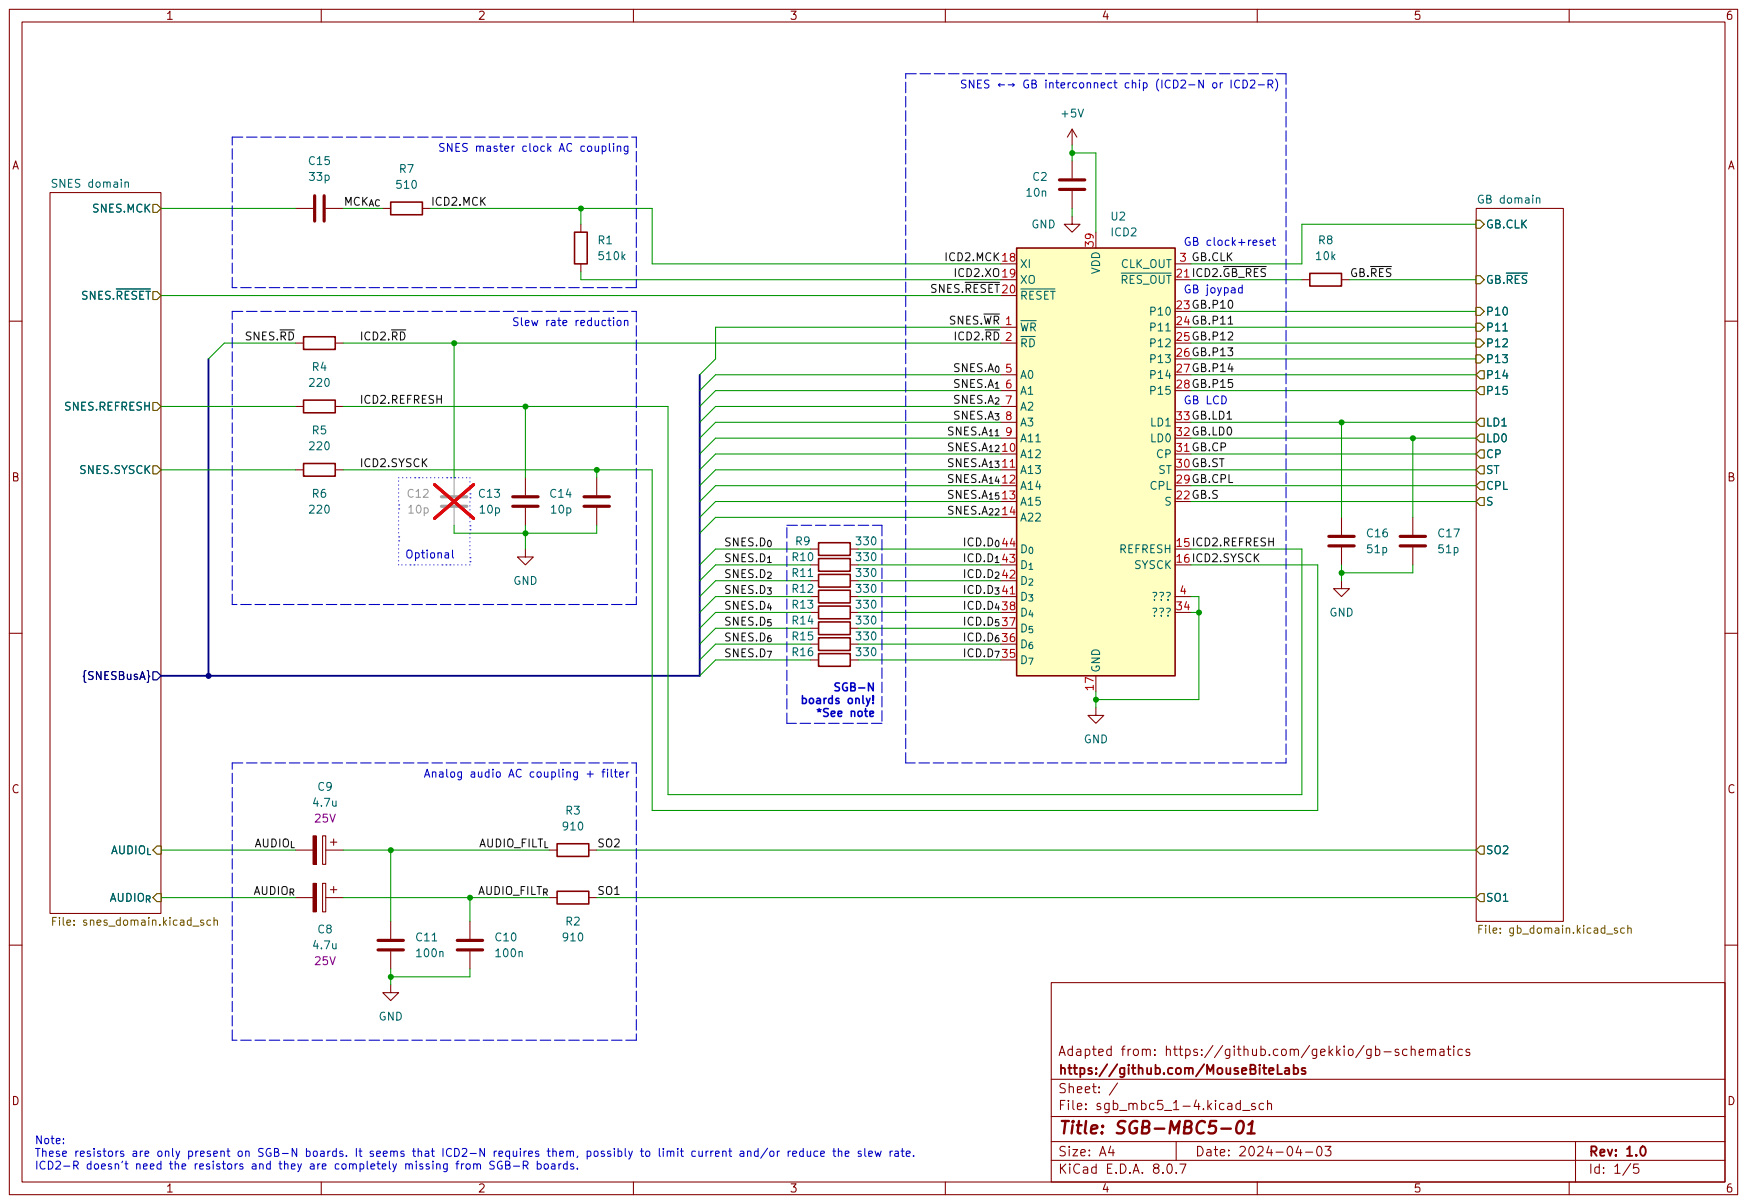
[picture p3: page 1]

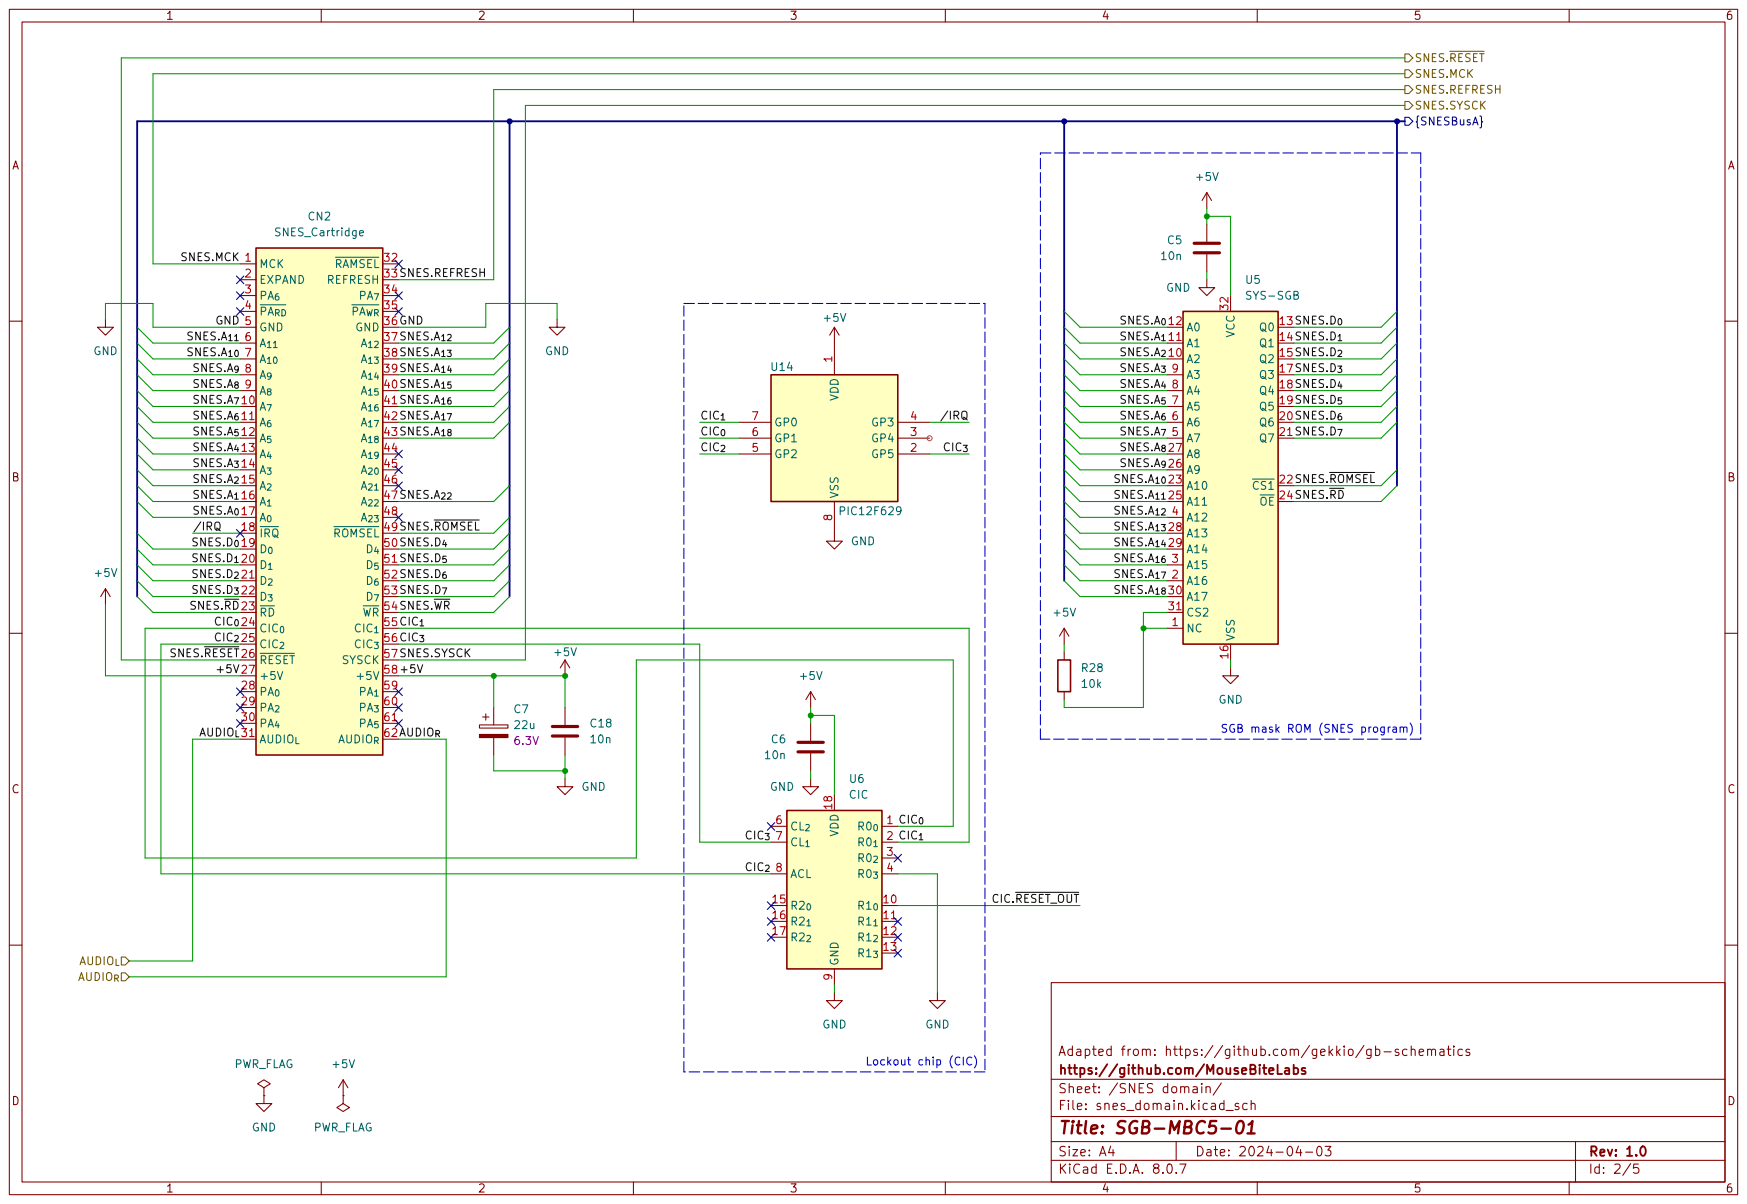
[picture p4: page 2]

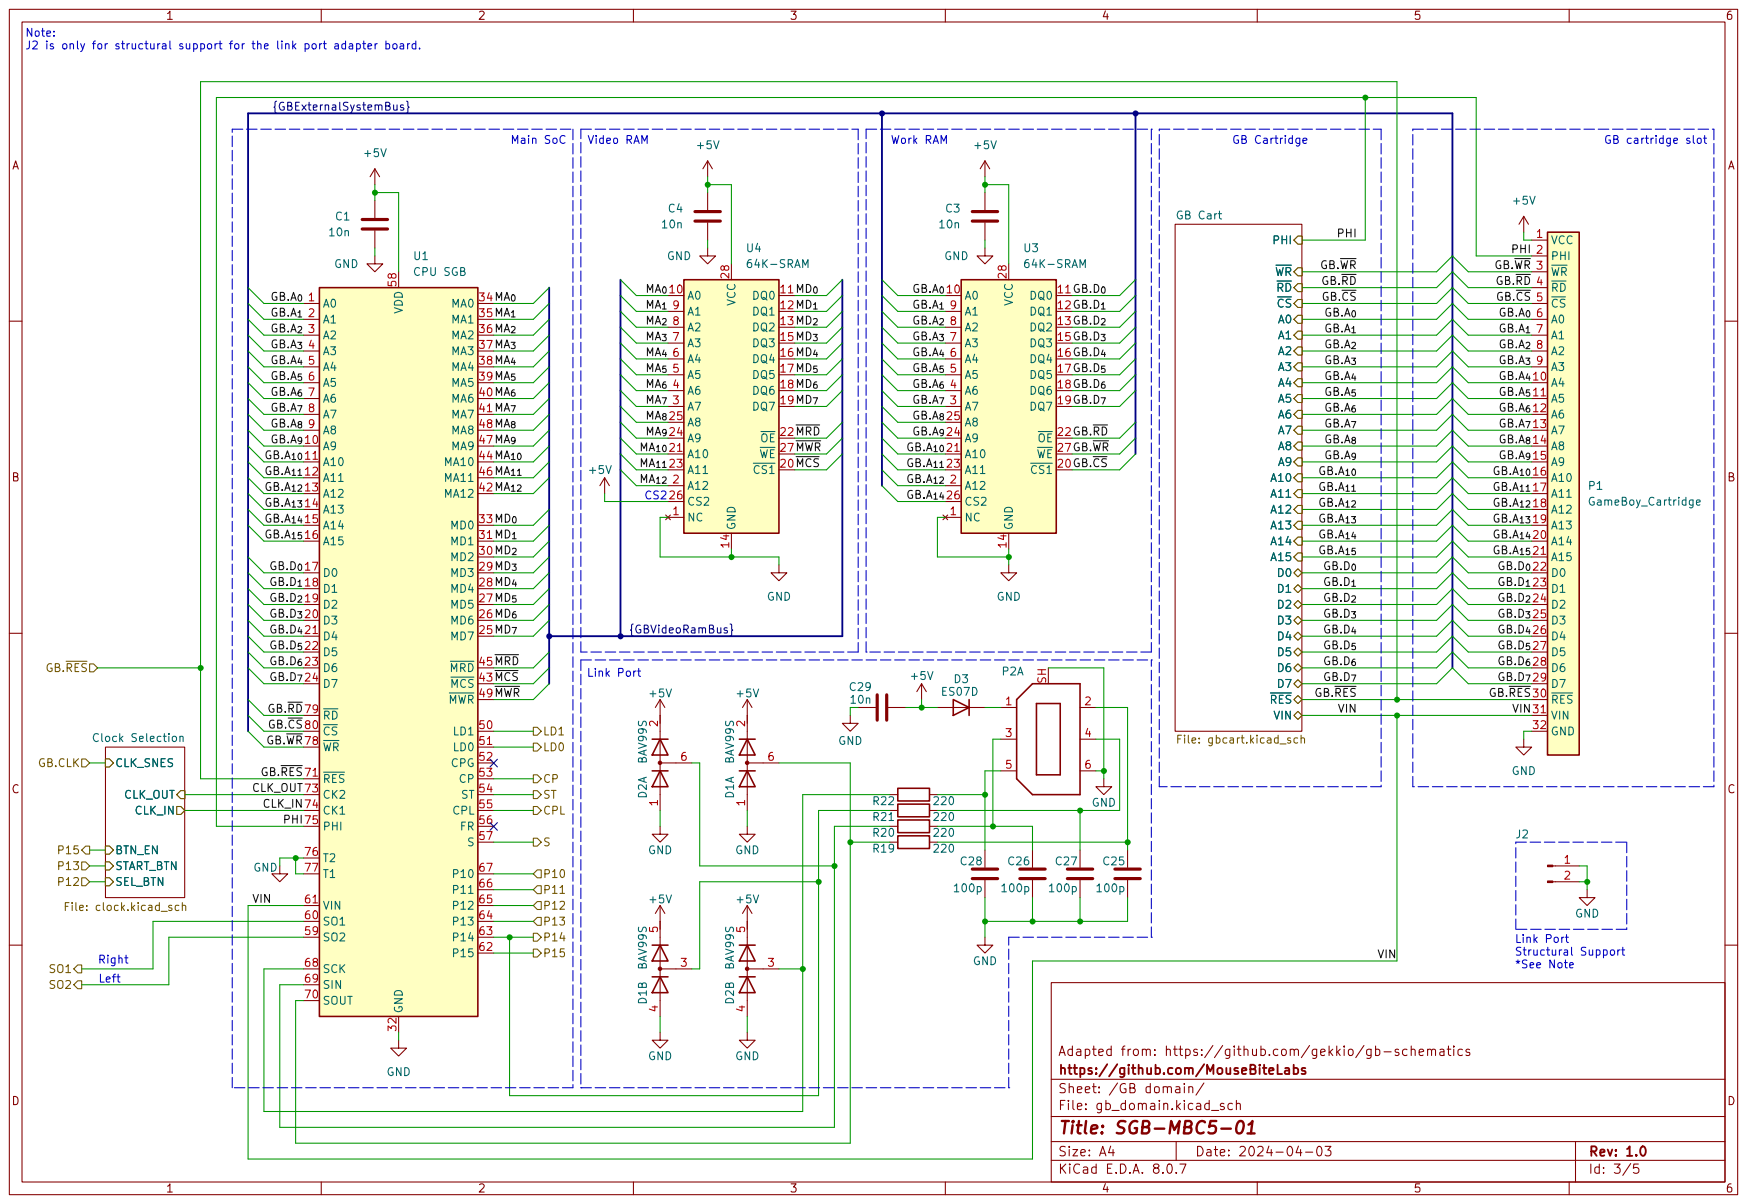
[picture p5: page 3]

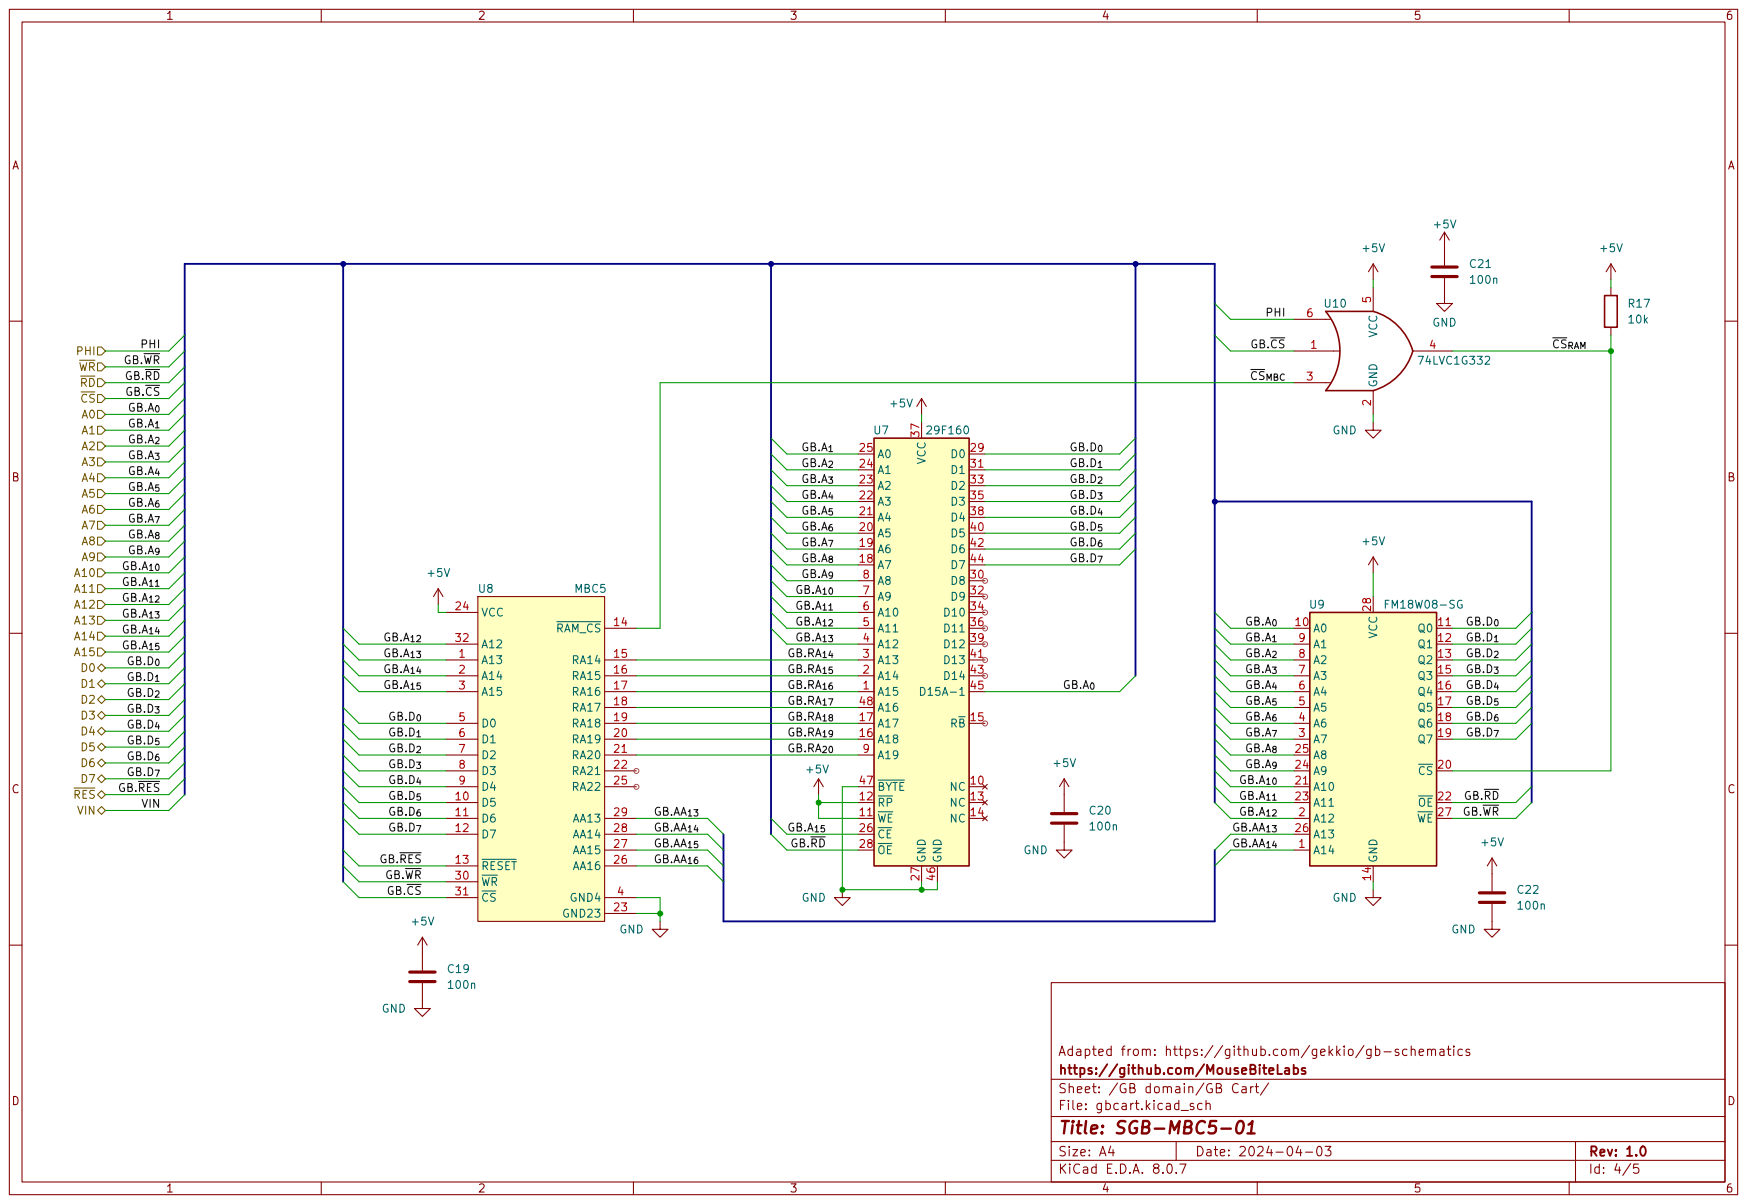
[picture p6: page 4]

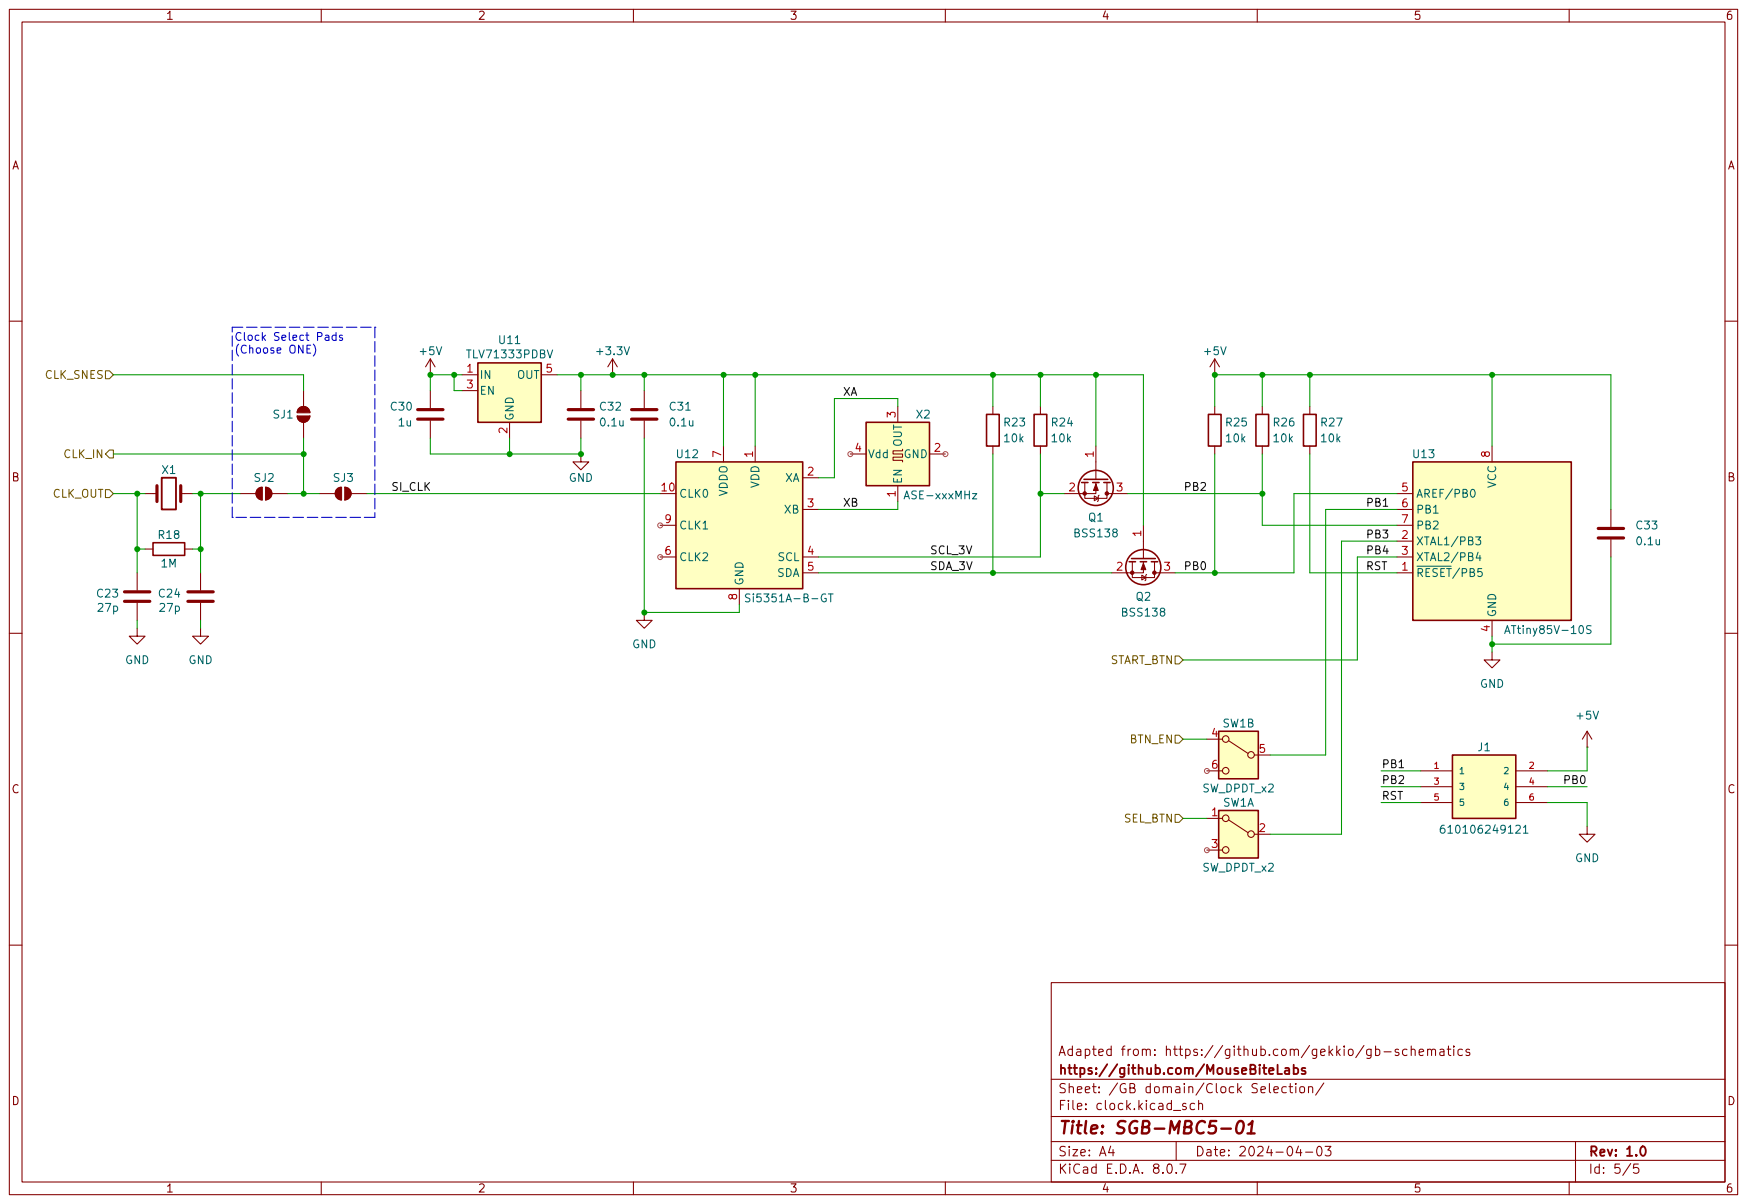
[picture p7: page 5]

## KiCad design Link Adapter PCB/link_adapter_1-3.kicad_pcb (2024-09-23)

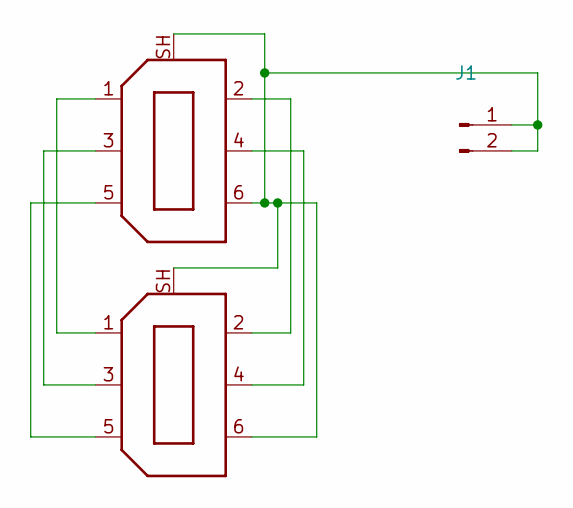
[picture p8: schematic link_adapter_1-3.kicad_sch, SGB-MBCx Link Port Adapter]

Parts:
J1: Conn_01x02_Pin; PinHeader_1x02_P2.54mm_Vertical
P1, P2: LINKPORTCGB-LINK; GameBoy_LinkPort_MGB_Horizontal

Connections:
unnamed: J1.1, J1.2, P1.6 (GND), P1.SH, P2.6 (GND), P2.SH
unnamed: P1.1 (+5V), P2.1 (+5V)
unnamed: P1.5 (CLK), P2.5 (CLK)
unnamed: P1.3 (IN), P2.3 (IN)
unnamed: P1.2 (OUT), P2.2 (OUT)
unnamed: P1.4 (SD), P2.4 (SD)

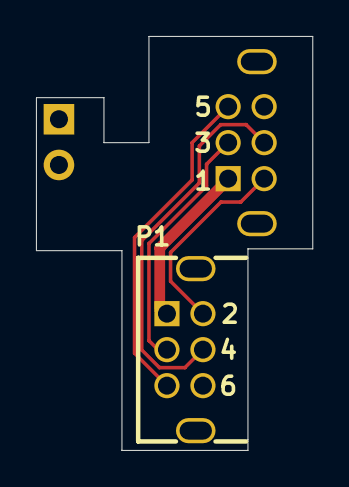
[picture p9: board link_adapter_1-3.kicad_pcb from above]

Board: 2 copper layers, 15.3 x 23.0 mm, 3 parts (1 on the bottom side), 6 nets.

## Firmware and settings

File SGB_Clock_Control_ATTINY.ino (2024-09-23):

//#include "si5351.h"
//#include "Wire.h"

//#include <si5351-avr-tiny-minimal.h>
//#include <USI_TWI_Master.h>

// FOR USE WITH ATTINY85

#include <Adafruit_SI5351.h>

Adafruit_SI5351 clockgen = Adafruit_SI5351();

const int base_clock_factor = 166;                                                                                    // Yields correct clock speed of 4.193 MHz with a clock_speed_factor of 1
const int array_length = 7;                                                                                           // Set how many clock speed settings are stored
const float clock_speed_factor[array_length] = {0.5,0.67,0.8,1,1.25,1.5,2};                                           // Array of clock DIVIDERS (lower number = faster; i.e. factor of 0.5 means it's 2x faster)
const int clock_default = 3;                                                                                          // Default speed factor setting
int clock_selection = clock_default;                                                                                  // Default speed factor selection - remember list is 0-indexed
int clock_speed = base_clock_factor;                                                                                  // Default clock divider factor for normal frequency

byte button_state;                                                                                                    // Used for storing sampled buttons when P15 falls

int button_count = 0;                                                                                                 // Variable for timing how long buttons are held
const int base_count = 1500;                                                                                          // Count value before clock speed changes for default clock speed
const int count_max[array_length] = {base_count,base_count,base_count,base_count,base_count,base_count,base_count};   // The delays before changing clock speeds for each speed setting. Default is to set them all equal, as the timing is 
                                                                                                                      //  driven by the micro's clock, not the SGB clock, but sometimes button state collection skips at higher speeds.
int start_pressed_first = 0;                                                                                          // Flag sets to 1 if start button is pressed before select
int select_pressed_first = 0;                                                                                         // Flag sets to 1 if select button is pressed before start

int disable_count = 0;                                                                                                // Disable timer variable
int disable_flag = 0;                                                                                                 // If 0, clock changing is enabled; if 1, clock changing is disabled
const int base_disable_count = base_count*2;                                                                          // How long pressing start+select at the same time to disable clock changing takes
int able2disable_flag = 1;                                                                                            // Flag used to prevent toggling of enable/disable of clock changing that would happen when holding start+select down for too long

const int debounce_delay = 100;                                                                                       // Allow delay between pressing start+select at the "same time"
int debounce_count = 0;                                                                                               // Variable for debouncing counter

void setup(void)
{
  //Serial.begin(9600);
  //pinMode(35,INPUT); //P12, PC2                                                                // Select
  //pinMode(34,INPUT); //P13, PC3                                                                // Start
  //pinMode(32,INPUT); //P15, PC5                                                                // Pin that polls face buttons
  pinMode(PCINT3,INPUT);  // P12, PB3 on pin 2 (FROM PC2)
  pinMode(PCINT4,INPUT);  // P13, PB4 on pin 3 (FROM PC3)
  pinMode(PCINT1,INPUT);  // P15, PB1 on pin 6 (FROM PC5)
  
  // SCL is pin 7 of the ATTINY85
  // SDA is pin 5 of the ATTINY85

  if (clockgen.begin() != ERROR_NONE)                                                     // Initialize clock chip
  {
    while(1);                                                                             // Loop forever if clock chip is not responding
  }

  clockgen.setupPLL(SI5351_PLL_A, 27, 332101, 390625);                                    // Set frequency to ( 25 MHz * (27 + 332101/390625) ...
  clockgen.setupMultisynth(0, SI5351_PLL_A, base_clock_factor,0,1);                       //  ... ) / 166 = 4.194304 MHz
  clockgen.enableOutputs(true);                                                           // Enable clock
}

void loop(void){
  if((clock_selection < 0) || (clock_selection > (array_length-1))){                      // If clock selection is outside range of array
    clock_selection = clock_default;                                                      // Reset clock selection
  }
  
  if((PINB&B00000010)==0){                                                                 // If P15 is low
    button_state = PINB;                                                                  // Store button states into this variable before P15 rises again    
    if((button_state&B00000010)==0){                                                       // Make sure P15 was captured, sometimes the delay between the previous two lines of code is too long and P15 rises back to 1
      if((button_state&B00010000)==0 && (button_state&B00001000) != 0){                   // If when P15 is polled, the start but not the select button is pressed
        debounce_count++;                                                                 // Increase debounce timer
        if(debounce_count > debounce_delay){                                              // Debounce timer for pressing start and select "simultaneously"
          select_pressed_first = 0;                                                       // Clear select flag if not already cleared
          start_pressed_first = 1;                                                        // Set start flag          
        }
      //Serial.println("Start pressed first!");
      }
      if((button_state&B00010000)!=0 && (button_state&B00001000) == 0){                   // If when P15 is polled, the select but not the start button is pressed
        debounce_count++;                                                                 // Increase debounce timer
        if(debounce_count > debounce_delay){                                              // Debounce timer for pressing start and select "simultaneously"
          start_pressed_first = 0;                                                        // Clear start flag if not already cleared
          select_pressed_first = 1;                                                       // Set select flag
        }
      //Serial.println("Select pressed first!");
      }
      if((button_state&B00010000)!=0 && (button_state&B00001000) != 0){                   // If when P15 is polled, neither start or select are pressed
        start_pressed_first = 0;                                                          // Reset flags back to 0
        select_pressed_first = 0;
        debounce_count = 0;                                                               // Reset debounce counter
        button_count = 0;                                                                 // Reset button hold timer
        disable_count = 0;                                                                // Reset disable timer counter
        able2disable_flag = 1;                                                            // Allow clock mod to mod clock
      //Serial.println("Buttons released!");
      }
      if((button_state&B00011000) == 0){                                                  // If both start and select are pressed
        //Serial.print("Both buttons pressed ");
        debounce_count = 0;                                                               // Reset debounce timer
        if(start_pressed_first == 0 && select_pressed_first == 0){                        // If neither start nor select were pressed first (aka, they were both pressed within the debounce timer interval)
          //Serial.print("at the same time");
          disable_count++;                                                                // Increment disable counter
          //Serial.print(disable_count,DEC);
          //Serial.println("");
          if((disable_count > base_disable_count) && able2disable_flag == 1){             // If the disable timer has passed the timeout, and you've let go of start+select from last time you disabled/enabled
            able2disable_flag = 0;                                                        // Prevent toggling of disabling/enabling
            if(disable_flag == 0){                                                        // If currently enabled...
              //digitalWrite(13,HIGH);
              disable_flag = 1;                                                           //  ... disable ...
              //Serial.println("Disabled");               
            }else{                                                                        //  ... otherwise ...
              //digitalWrite(13,LOW);
              disable_flag = 0;                                                           //  ... enable again
              //Serial.println("Enabled");
            }
            clock_selection = clock_default;                                              // Reset the clock selection variable to default
            clock_speed = base_clock_factor;                                              // Reset clock speed to default
            button_count = 0;                                                             // Reset button hold counter
            disable_count = 0;                                                            // Reset disable counter
            clockgen.enableOutputs(false);                                                // Pause clock output
            clockgen.setupPLL(SI5351_PLL_A, 27, 332101, 390625);                          // Set up PLL
            clockgen.setupMultisynth(0, SI5351_PLL_A, clock_speed,0,1);                   // Set up multiplier
            clockgen.enableOutputs(true);                                                 // Enable clock output
          }
        }else{
          disable_count = 0;                                                              // Reset disable counter
          button_count++;                                                                 // Increase button hold counter
          if(button_count > int(count_max[clock_selection])){                             // If counter has reached time limit
            if(start_pressed_first == 1){                                                 // If start was pressed first
              //Serial.print("Slow down!");
              //Serial.println("");
              if(clock_selection != (array_length-1)){                                    // Prevent increasing past array limit
                clock_selection++;                                                        // Increase clock speed setpoint
                //Serial.println(clock_selection,DEC);
                clock_speed = int(base_clock_factor*clock_speed_factor[clock_selection]); // Calculate new clock speed
                if(disable_flag == 0){                                                    // If clock changing is not disabled
                  clockgen.enableOutputs(false);                                          // Pause clock output
                  clockgen.setupPLL(SI5351_PLL_A, 27, 332101, 390625);                    // Set up PLL
                  clockgen.setupMultisynth(0, SI5351_PLL_A, clock_speed,0,1);             // Set up multiplier
                  clockgen.enableOutputs(true);                                           // Enable clock output
                  //Serial.println("Changed clock!");
                }else{
                  //Serial.println("Clock change is disabled!");
                }
              }
            }
            if(select_pressed_first == 1){                                                // If select was pressed first, do the same thing as above but slowing down instead
              //Serial.print("Speed up!");
              //Serial.println("");
              if(clock_selection != 0){  
                clock_selection--;
                //Serial.println(clock_selection,DEC);
                clock_speed = int(base_clock_factor*clock_speed_factor[clock_selection]); 
                if(disable_flag == 0){
                  clockgen.enableOutputs(false);
                  clockgen.setupPLL(SI5351_PLL_A, 27, 332101, 390625);
                  clockgen.setupMultisynth(0, SI5351_PLL_A, clock_speed,0,1);
                  clockgen.enableOutputs(true); 
                  //Serial.println("Changed clock!");
                }else{
                  //Serial.println("Clock change is disabled!");
                }
              }             
            }
            button_count = 0;                                                             // After changing the clock speed, reset the counter
            //Serial.println("Reset button counter");
          }
        }
      }else{
        disable_count = 0;                                                                // Reset disable counter
        //Serial.println("Reset disable counter");
      }
    }else{                                                                                // If P15 triggered the loop, but polling button states doesn't show P15 low (micro was too slow)
      //Serial.println("missed!");                                                        
    }
  }

  //Serial.println(clock_speed,DEC);

}
